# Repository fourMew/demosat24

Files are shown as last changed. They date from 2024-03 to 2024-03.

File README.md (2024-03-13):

# ACC Demosat 2024 - Closed chamber O3 testing
A low budget payload for testing the effect of fluorocarbons/fluorocarbon like substances on ozone in the upper atmosphere.
 <br/>
 
# How to use this repo
clone the repo, either by running:
```sh
git clone https://github.com/fourMew/demosat24.git
```
or by downloading and extracting the zip:

firefox_V28YIlp0Gu

## Arduino
To use this sketch you must download and install the [DFRobot_OzoneSensor library](https://codeload.github.com/DFRobot/DFRobot_OzoneSensor/zip/master)

*How do I [install an arduino library](https://www.arduino.cc/en/Guide/Libraries#.UxU8mdzF9H0)?*

From here you should be able to open the sketch file demosat24/code/demosat/demosat.ino with the Arduino IDE

This sketch currently supports:

 - Dual O3 sensors via I2C Addresses **0x73** and **0x72**
 - 1 SSCDANN150PGAA5 5v pressure sensor via analog pin **A3**
 - 1 3.3v temp sensor via analog pin **A0**

## KiCAD
With KiCAD, just open the project file demosat24/pcb/shield/demosatShield.kicad_pro

If you get errors or parts of the schematic are not showing up, ensure that the symbols and footprints in the project specific library are properly loaded

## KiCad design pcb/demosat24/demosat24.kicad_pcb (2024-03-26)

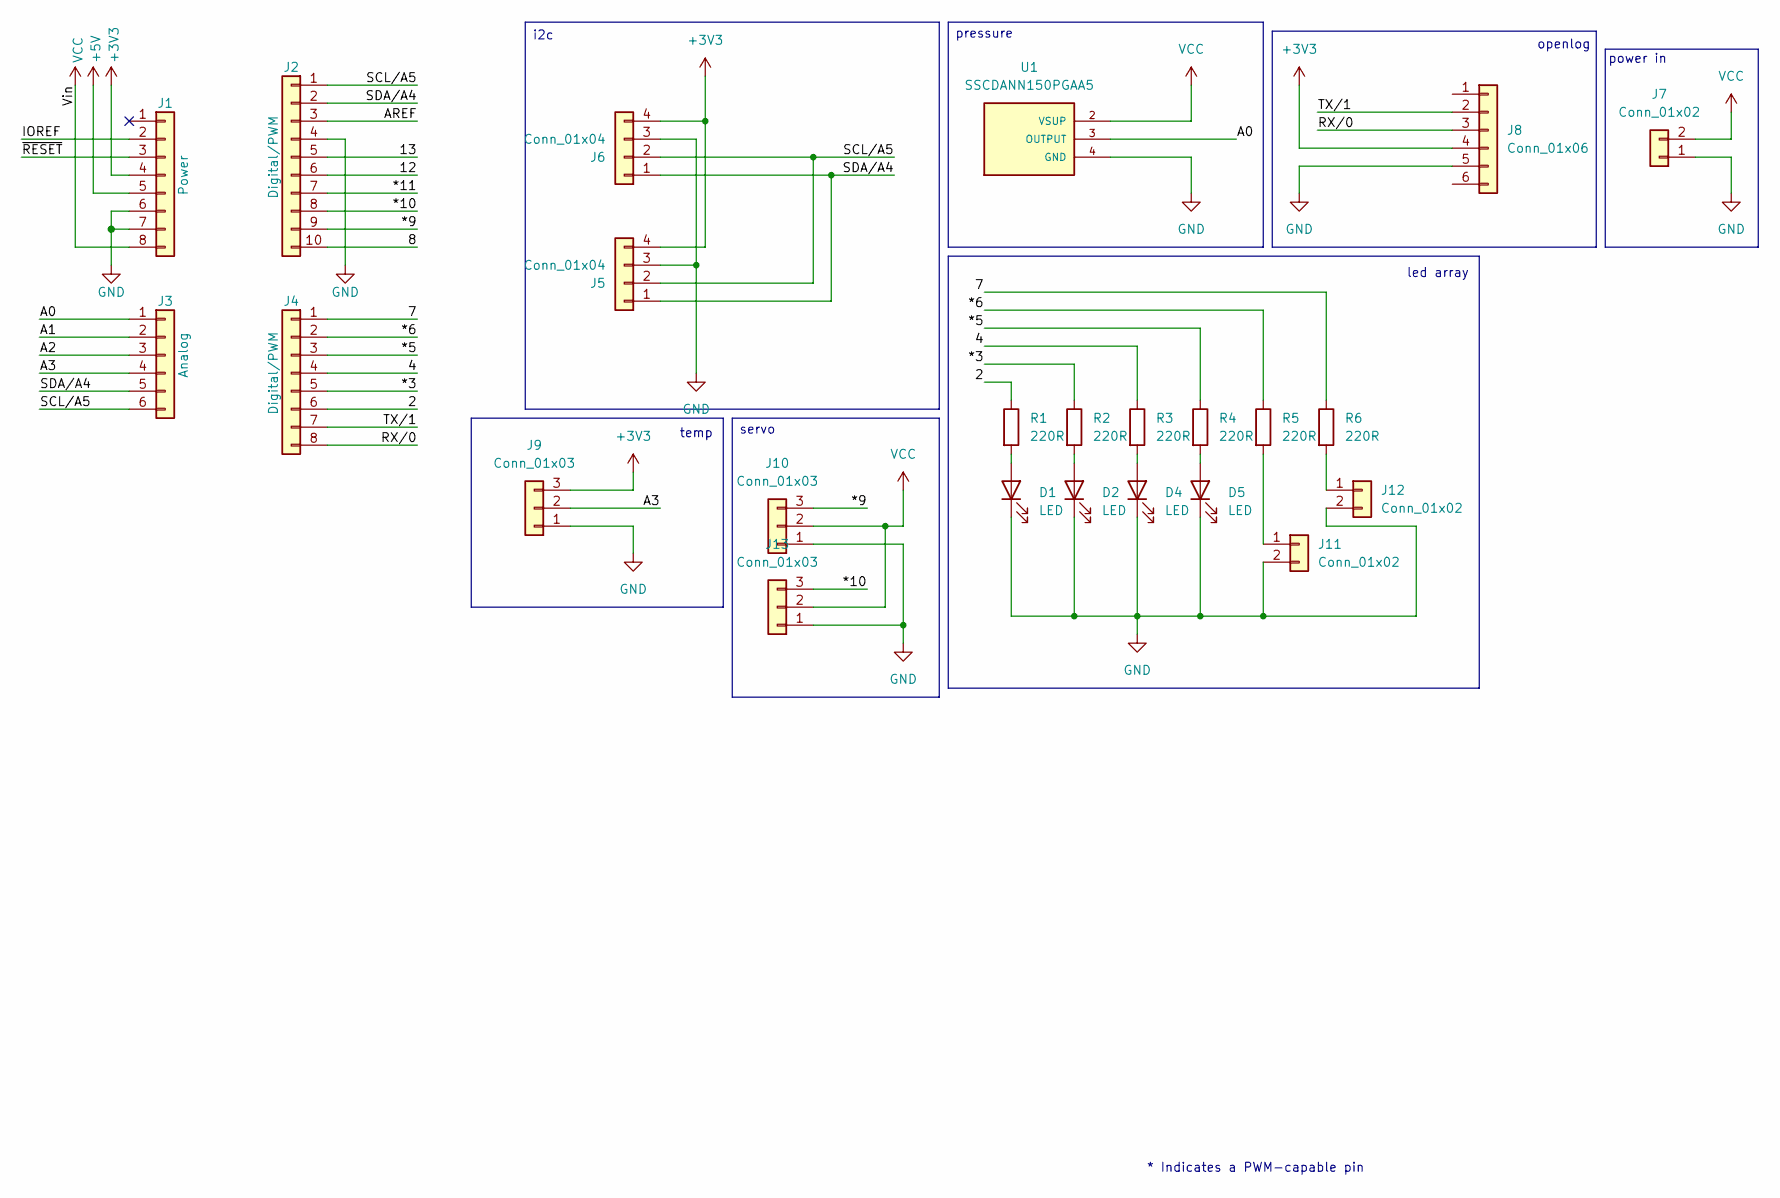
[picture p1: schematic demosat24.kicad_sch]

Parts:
D1, D2, D4, D5: LED; LED_D5.0mm
J1: Power; PinSocket_1x08_P2.54mm_Vertical
J2: Digital/PWM; PinSocket_1x10_P2.54mm_Vertical
J3: Analog; PinSocket_1x06_P2.54mm_Vertical
J4: Digital/PWM; PinSocket_1x08_P2.54mm_Vertical
J5, J6: Conn_01x04; JST_PH_S4B-PH-K_1x04_P2.00mm_Horizontal
J7: Conn_01x02; JST_PH_B2B-PH-K_1x02_P2.00mm_Vertical
J8: Conn_01x06; PinSocket_1x06_P2.54mm_Vertical
J9: Conn_01x03; Molex_SL_171971-0003_1x03_P2.54mm_Vertical
J10, J13: Conn_01x03; PinHeader_1x03_P2.54mm_Vertical
J11, J12: Conn_01x02; PinHeader_1x02_P2.54mm_Vertical
R1, R2, R3, R4, R5, R6: 220R; R_Axial_DIN0207_L6.3mm_D2.5mm_P7.62mm_Horizontal
U1: SSCDANN150PGAA5; XDCR_SSCDANN150PGAA5

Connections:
+3V3: J1.4, J5.4, J6.4, J8.4, J9.3
+5V: J1.5
/2: J4.6, R1.1
/4: J4.4, R3.1
/7: J4.1, R6.1
/8: J2.10
/12: J2.6
/13: J2.5
/*3: J4.5, R2.1
/*5: J4.3, R4.1
/*6: J4.2, R5.1
/*9: J2.9, J10.3
/*10: J2.8, J13.3
/*11: J2.7
/A0: J3.1, U1.3 (OUTPUT)
/A1: J3.2
/A2: J3.3
/A3: J3.4, J9.2
/AREF: J2.3
/IOREF: J1.2
/RX/0: J4.8, J8.3
/SCL/A5: J2.1, J3.6, J5.2, J6.2
/SDA/A4: J2.2, J3.5, J5.1, J6.1
/TX/1: J4.7, J8.2
/~RESET: J1.3
GND: D1.1 (K), D2.1 (K), D4.1 (K), D5.1 (K), J1.6, J1.7, J2.4, J5.3, J6.3, J7.1, J8.5, J9.1, J10.1, J11.2, J12.2, J13.1, U1.4 (GND)
unnamed: D1.2 (A), R1.2
unnamed: D2.2 (A), R2.2
unnamed: D4.2 (A), R3.2
unnamed: D5.2 (A), R4.2
unnamed: J11.1, R5.2
unnamed: J12.1, R6.2
VCC: J1.8, J7.2, J10.2, J13.2, U1.2 (VSUP)

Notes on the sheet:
pressure
led array
servo
temp
power in
* Indicates a PWM-capable pin
i2c
openlog

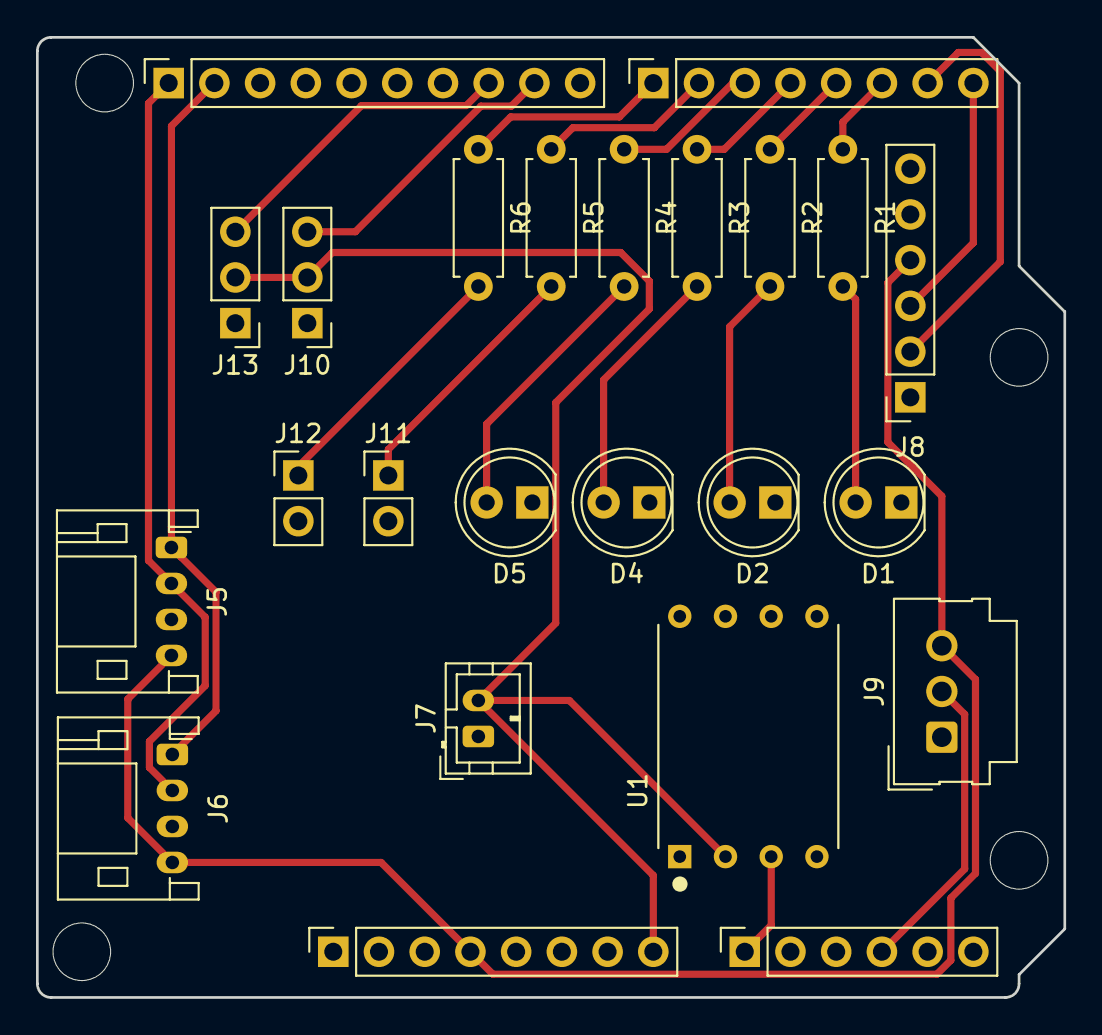
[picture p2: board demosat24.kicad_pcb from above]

Board: 2 copper layers, 57.1 x 53.3 mm, 28 parts (0 on the bottom side), 23 nets.

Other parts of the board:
MH1, MH2, MH3, MH4: MountingHole_3.2mm

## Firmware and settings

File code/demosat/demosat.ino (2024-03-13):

#include <DFRobot_OzoneSensor.h>

#define COLLECT_NUMBER 20 //what is this? <-> collect number, the collection range is 1-100

#define OZONE1_ADDR OZONE_ADDRESS_3 //ozone1 at i2c address 0x73
#define OZONE2_ADDR OZONE_ADDRESS_2 //ozone2 at i2c address 0x72
/*   iic slave Address, The default is ADDRESS_3
       ADDRESS_0               0x70      // iic device address
       ADDRESS_1               0x71
       ADDRESS_2               0x72
       ADDRESS_3               0x73
*/

// declare sensor classes
DFRobot_OzoneSensor Ozone1;
DFRobot_OzoneSensor Ozone2;

int pressure;
float pressureVolt;
float psi;

int temp1;
float temp1Volt;
float temp1C;
float temp1F;

void setup() {
  Serial.begin(9600);

  while (!Ozone1.begin(OZONE1_ADDR)) {
    Serial.println("I2c device number error on 0x73");
    delay(1000);
  }
  while (!Ozone2.begin(OZONE2_ADDR)) {
    Serial.println("I2c device number error on 0x72");
    delay(1000);
  }
  Serial.println("I2c connect success !");

  Ozone1.setModes(MEASURE_MODE_PASSIVE);
  Ozone2.setModes(MEASURE_MODE_PASSIVE);
  /*   Set iic mode, active mode or passive mode
       MEASURE_MODE_AUTOMATIC            // active  mode
       MEASURE_MODE_PASSIVE              // passive mode
  */
}

void loop() {
  int16_t intO3 = Ozone1.readOzoneData(COLLECT_NUMBER);
  int16_t extO3 = Ozone2.readOzoneData(COLLECT_NUMBER);
  /*   Smooth data collection
       COLLECT_NUMBER                    // The collection range is 1-100
  */
  temp1 = analogRead(A0);
  temp1Volt = temp1*(5.0/1023);
  temp1C = (temp1Volt - 0.5)/(0.01);
  temp1F = (temp1C*(9.0/5.0) + 32);

  pressure = analogRead(A3);
  pressureVolt = pressure*(5.0/1023);
  psi = (pressureVolt-0.5)*(15.0/4.0); 

  Serial.print("Temp: ");
  Serial.print(temp1F, 2);
  Serial.print("F, PSI: ");
  Serial.print(psi, 2);
  Serial.print(" PSI, Ozone concentration: ");
  Serial.print(intO3);
  Serial.print(" PPB inside, ");
  Serial.print(extO3);
  Serial.println(" PPB outside.");
  delay(1000);
}

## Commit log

2024-03-13 Added current Arduino sketch with support for analog pressure and temp, and dual o3 over i2c
2024-03-13 updated kicad project: schematic for sensors
    [demosatShield.kicad_sch]
2024-03-13 kicad: cleaned up, moved all leds to the lower digital header, added socket for openlog
    [demosatShield.kicad_sch]
2024-03-14 new kicad project file: new schematic started, pcb started in the new project file
    [demosat24.kicad_pcb, demosat24.kicad_sch]
2024-03-14 reorganized schematic slightly
    [demosat24.kicad_sch]
2024-03-18 complete schematic added
    [demosat24.kicad_sch]
2024-03-19 pcb with one servo, all data and power connected but not ground
    [demosat24.kicad_pcb, demosat24.kicad_sch]
2024-03-19 minor changes to pcb
    [demosat24.kicad_pcb, demosat24.kicad_sch]
2024-03-20 PCB Ordered! switched to dual layer board with ground plane added headers for a second servo cleaned up repo
    [demosat24.kicad_sch, demosat24singleLayer.kicad_pcb, demosatShield.kicad_pcb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]
2024-03-20 new 1 layer pcb layout
    [new1layer.kicad_pcb]
2024-03-26 updated pcb design with information learned from assembling the board
    [demosat24.kicad_pcb, demosat24.kicad_sch]
